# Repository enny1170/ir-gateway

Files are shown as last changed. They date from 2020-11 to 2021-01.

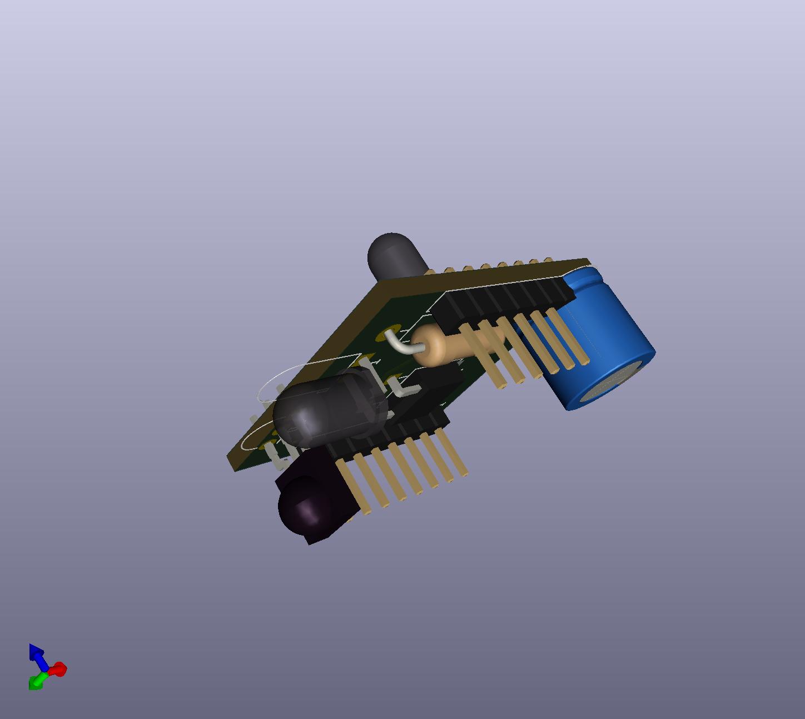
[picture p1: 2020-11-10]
shematics/kicad/RcOid/RcOid/RcOid.jpg

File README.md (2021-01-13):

# Introduction 
This is a fork of the famous [ESP8266-RcOid](https://www.rcoid.de/ESP8266.html) Project

the Hardware is changed to a Wemos D1 mini pro alternativly Wemos D1 32 (pincompatible) and the is software updated to support this.
And a custom Board are developed. To easy hookup this on the Module.
Most parts are rewritten, because I want to use this also as IR-Gateway togeter with my Smart-Home.
So we change to ESP Async-Webser and AsyncMQTT. Adding a better WebUI to support Storage and Management of Codes via Web-Ui.

To have a good Support for multiple Clients at the same Device we have designet to work without any blocking functions.
All API's needed to support the Rcoid-App exist. So the App is fully suported.

This project contains also several shematics.
1. a circurit and a pcb to simply Hookup on the given Module. (shematics/kicad/) [IR-Shield](https://www.pcbway.com/project/shareproject/IR_Shield_for_wemos_D1_pro_or_Wemos_D1_32.html)
2. 3D printable STL-Files as for a Cover (shematic/3dprint)
3. a Freecad Project to build or modify the Case (shematic/freecad)

# Usage (extract from Device Readme)
    This Firmware is a complete new Implementation of the [Rcoid](https://rcoid.de/) Project.
    This implementation supports the same Interface for the RcOid App. Has a extended Web UI and REST-Api. Devices can be used as IR-Gateway trought MQTT. 

    Sending and reciving IR-Codes new implemented for blocking free work. Also the storage of IR-Codes (Commands) added. This Commands can be used for MQTT and REST. 
    Upload and Downlowad of stored commands are possible. 

    A new unconfigured Device will start in Accesspoint-Mode and provide a 'ESP8266 for RCoid Access Point' with Password passpass on IP 192.168.0.1. 
    You are able to setup SSID and Password for your local WiFi-Connection.
    From the Root-Page you have also the possibility tor reboot, remove Web Config, and reset to Factory.
    Only from this page you can enable IR-reciving to capture IR-Codes.
    From the MQTT Page you can ste the Connection to your MQTT-Server and a Prefix used for the topic on MQTT. If the MQTT-Server adress empty or a '.' the MQTT communication will be disabled.
    In MQTT-Broker the device will be provide its local IP-Adress and available commands. The device subscribes /[Prefix]/Cmd. If the device receive a String in this topic, this will be interpreted as a Command. 
    The device try to find this Command and will send the Code immedaly.
    The same Functionality can be reached by sending a GET-Request to /cmd?button=xxxx. Where xxxx the name of the command. It can be taken from the Command-Page.

    The Command page are selfexplanating. But two points you have to know. Editing a Command you have to set a Code and a Name. The Name will be used as Filename to store the command on device Flash.
    And also as Command to raise from MQTT. The Clock Icon on the Command-Page will give you the possibilty to setup one Timer to send this command later.

    Some devices needs to receive a Code multiple times. So we add a Option Repeat for stored Commands. This will repeat the IR-Output according to this setting. Minimum is 1 maximum 5.

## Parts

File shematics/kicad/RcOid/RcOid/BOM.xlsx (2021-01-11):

Reference | Description | Count
U1 | IR Receiver VS1838B | 1
R1 | Resistor 2.4 Ohm | 1
D1 / D2 | IR Sender TSAL6400 (normaly 1 will be used) | 1
Q1 | MOSFET IRLU024N | 1
C1 | ELCO 2000µF radial | 1

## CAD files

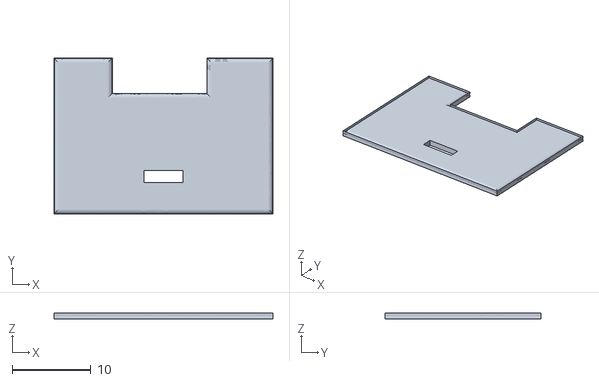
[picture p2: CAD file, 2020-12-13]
shematics/3dprint/RcDroidTop_V2.stl
27.8 x 19.8 x 0.8

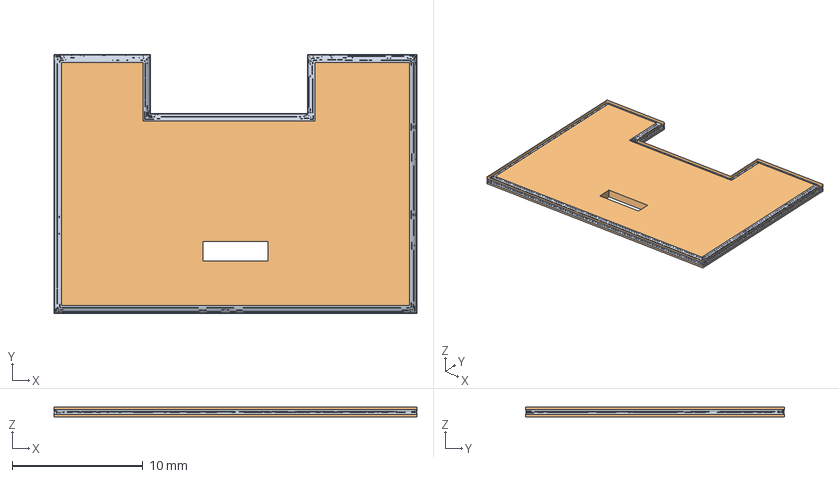
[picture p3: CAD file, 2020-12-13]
shematics/freecad/IrDroid_Case_V2.FCStd
27.8 x 19.8 x 0.8 mm
Top
Top001

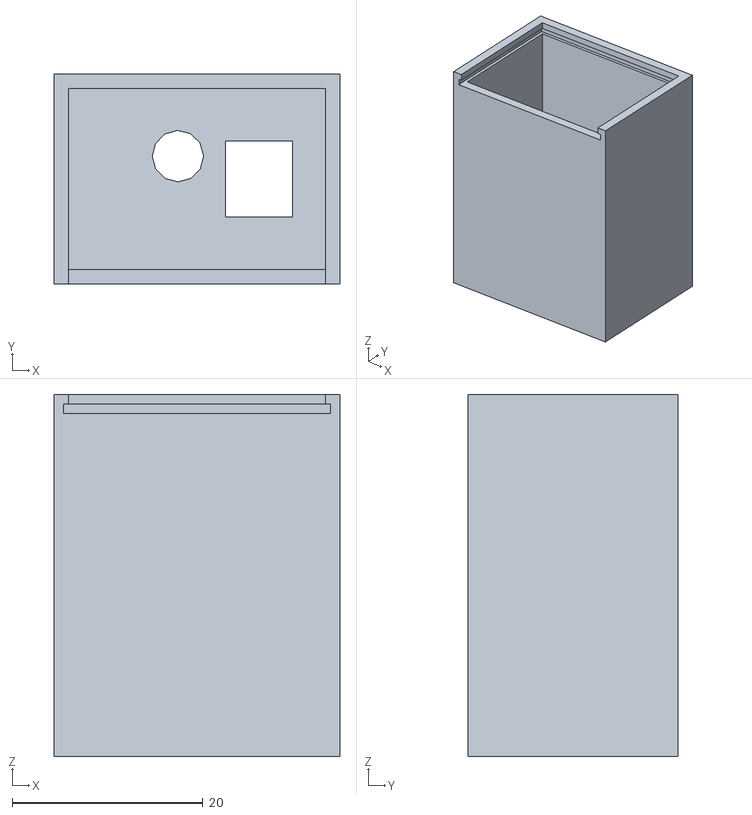
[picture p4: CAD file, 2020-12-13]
shematics/3dprint/RcDroidCase_V2.stl
30.0 x 22.0 x 38.0

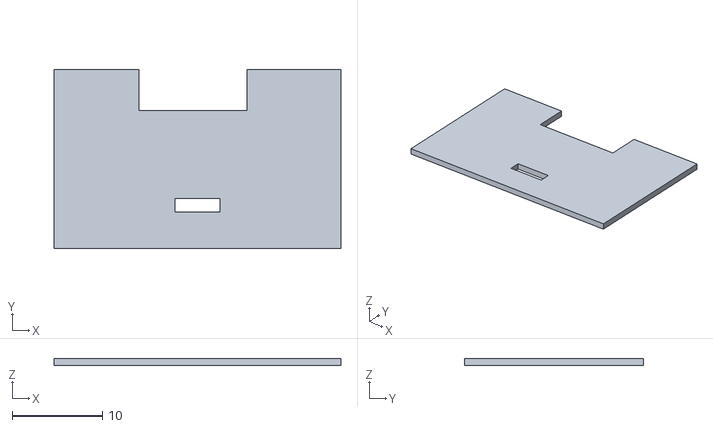
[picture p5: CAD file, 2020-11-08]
shematics/3dprint/IrDroidTop.stl
31.8 x 19.8 x 0.8

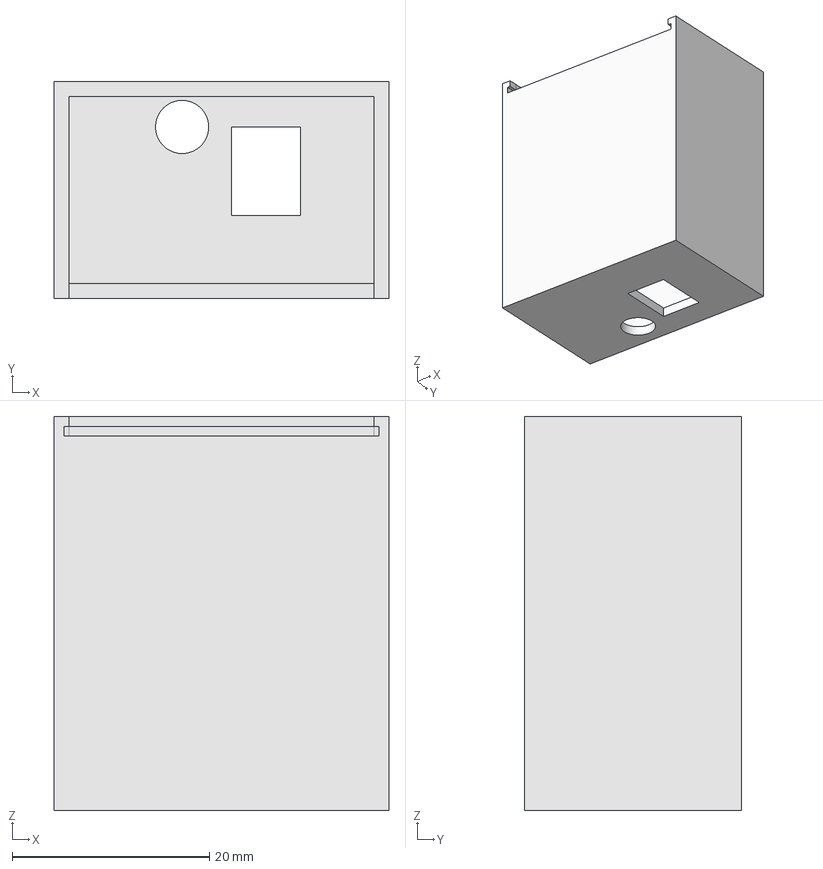
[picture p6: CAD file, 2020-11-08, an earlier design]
shematics/freecad/IrDroid_Case_V1.FCStd
34.0 x 22.0 x 40.0 mm

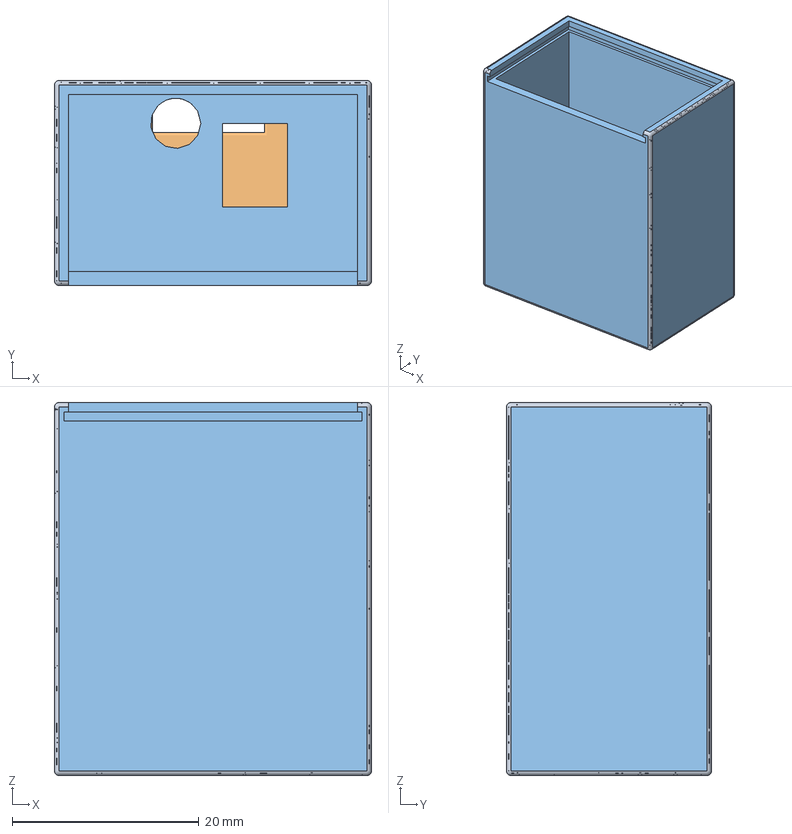
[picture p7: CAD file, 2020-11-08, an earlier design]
shematics/freecad/IrDroid_Case.FCStd
34.0 x 22.0 x 40.0 mm
Case
RcDroidTop_V1
RcDroidCase_V1

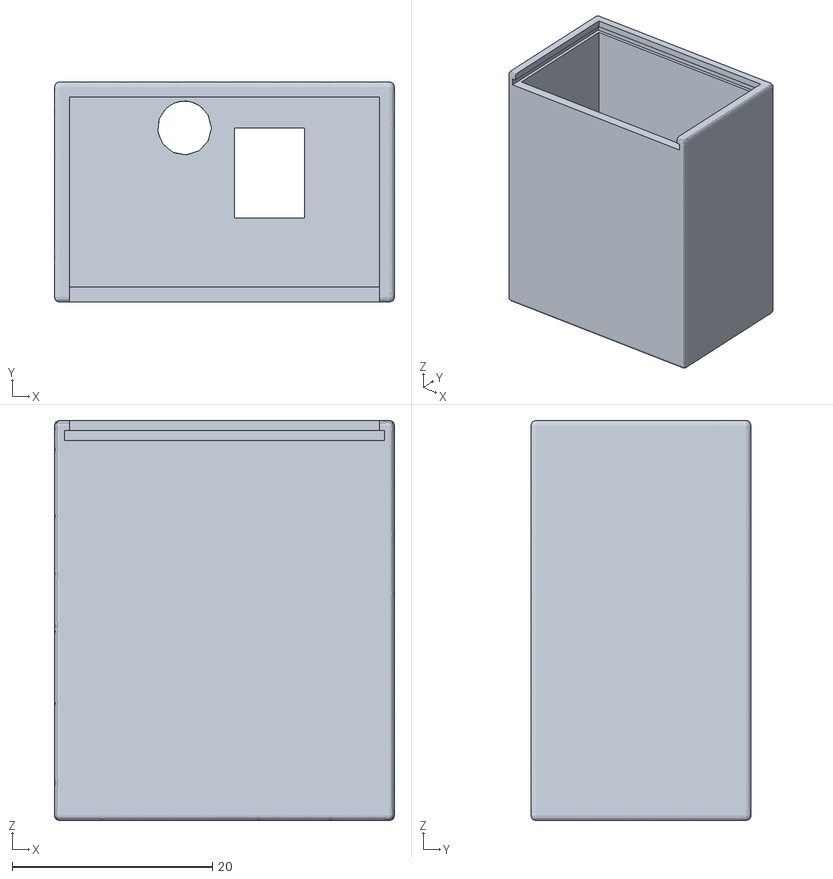
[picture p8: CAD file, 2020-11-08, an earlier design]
shematics/3dprint/RcDroidCase_V1.stl
34.0 x 22.0 x 40.0

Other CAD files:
shematics/3dprint/RcDroidTop_V1.stl
shematics/3dprint/IrDroidCase.stl

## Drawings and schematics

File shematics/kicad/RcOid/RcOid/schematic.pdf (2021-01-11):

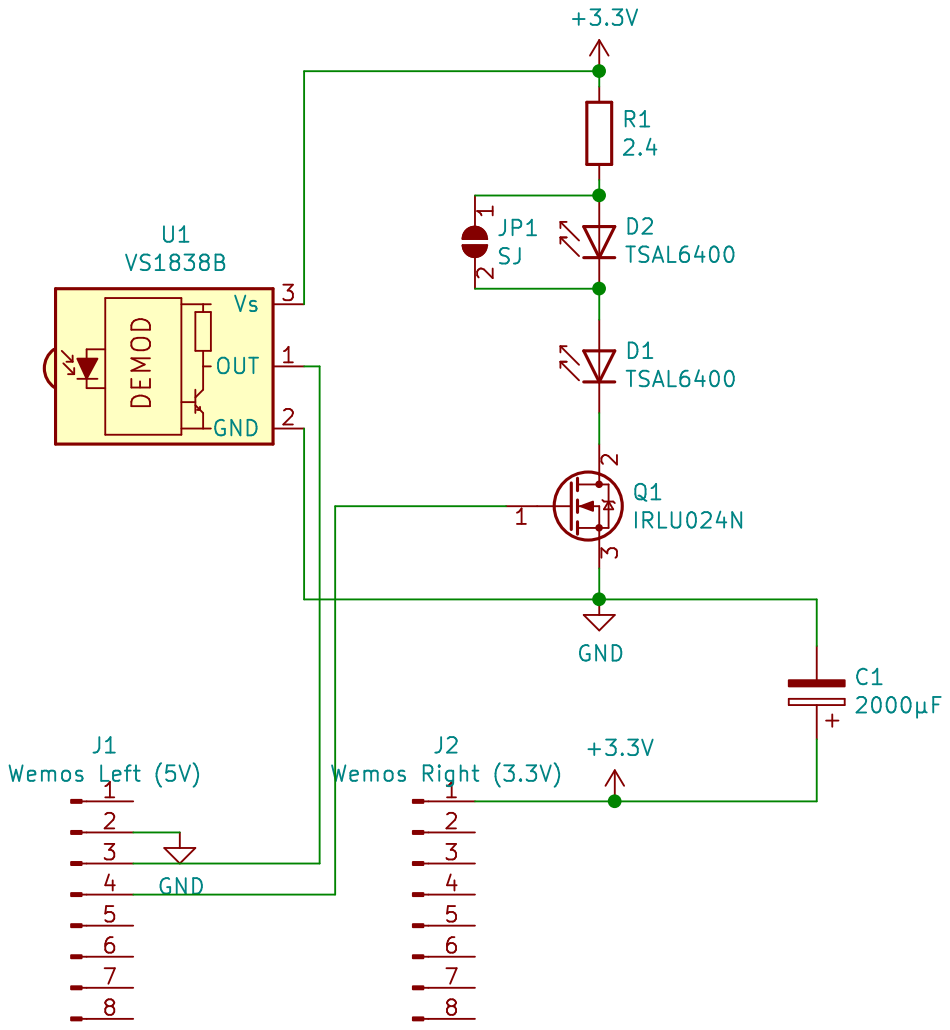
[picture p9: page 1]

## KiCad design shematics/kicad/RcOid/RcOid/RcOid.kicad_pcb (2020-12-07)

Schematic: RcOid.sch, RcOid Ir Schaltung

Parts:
C1: 2000µF; CP_Radial_D10.0mm_P2.50mm
D1: TRU 1577326; LED_D5.0mm_Horizontal_O1.27mm_Z3.0mm_IRGrey
D2: TRU 1577326; LED_D5.0mm_IRGrey
J1: Wemos Left (5V); PinHeader_1x08_P2.54mm_Vertical
J2: Wemos Right (3.3V); PinHeader_1x08_P2.54mm_Vertical
JP1: SJ; SolderJumper-2_P1.3mm_Open_Pad1.0x1.5mm
Q1: IRLU024N; TO-251-2-1EP_Horizontal_TabDown
R1: 47; R_Axial_DIN0411_L9.9mm_D3.6mm_P15.24mm_Horizontal
U1: TSOP531xx; Vishay_MINIMOLD-3Pin

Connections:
+3V3: C1.1, J2.1, R1.1, U1.3 (Vs)
GND: C1.2, J1.2, Q1.3 (S), U1.2 (GND)
unnamed: D1.1 (K), Q1.2 (D)
unnamed: D1.2 (A), D2.1 (K), JP1.2
unnamed: D2.2 (A), JP1.1, R1.2
unnamed: J1.3, U1.1 (OUT)
unnamed: J1.4, Q1.1 (G)

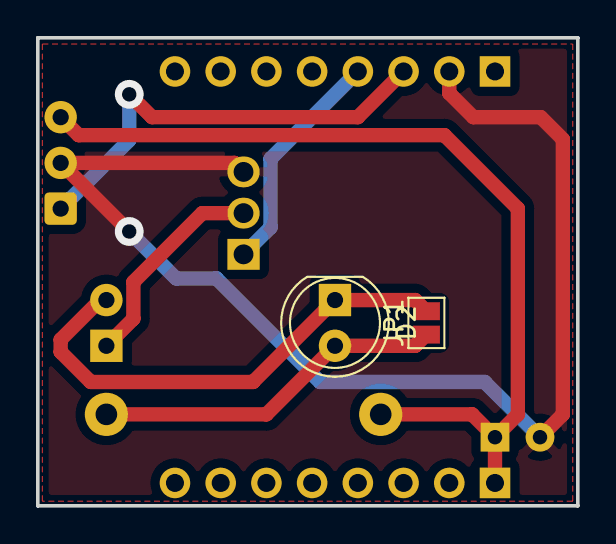
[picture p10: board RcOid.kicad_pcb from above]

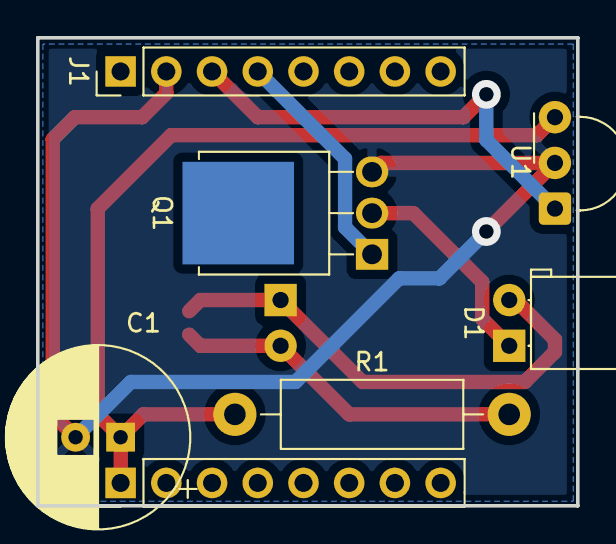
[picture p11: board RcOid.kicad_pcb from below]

Board: 2 copper layers, 30.0 x 26.0 mm, 9 parts (7 on the bottom side), 7 nets.

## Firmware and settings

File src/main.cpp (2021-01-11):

#include <WiFiClient.h>
#include <Arduino.h>
#ifdef ESP32
#include <WiFi.h>
#include <AsyncTCP.h>
#elif defined(ESP8266)
#include <ESP8266WiFi.h>
#include <ESPAsyncTCP.h>
#endif
#include <ESPAsyncWebServer.h>
#include <IRremoteESP8266.h>
#include <IRrecv.h>
#include <IRutils.h>
#include <ArduinoJson.h>
#include <Config.h>
#include <mqttconf.h>
#include <WebServerImpl.h>
#include <ircode.h>
#include <ircodes.h>
#include <mqttimpl.h>
#include <ArduinoOTA.h>

// The IR Hardware are defined in ircodes.h

// Netzwerkinformationen für Accesspoint
// Im AP-Modus ist der ESP8266 unter der IP 192.168.0.1 erreichbar
const char *ssidAP = "ESP8266 for RCoid Access Point";
const char *passwordAP = "passpass"; //Muss mindestens 8 Zeichen haben
//bool startMqtt=false;



/***********************************************************************************************************
    ////////////////////////////////////   SETUP Access Point  ///////////////////////////////////////////

    Create Soft AP.
    Settings:
        SSID = "ESP8266 for RCoid Access Point"
        Pass = "passpass"
        IP   = "192.168.0.1"

    Will be done if no Wifi configured.
************************************************************************************************************/
void setupAP(void)
{
  WiFi.mode(WIFI_AP_STA);

  serial_print_Networks();

  Serial.println("Setup Soft AP...");
  IPAddress apIP(192, 168, 0, 1);
  WiFi.softAPConfig(apIP, apIP, IPAddress(255, 255, 255, 0));

  WiFi.softAP(ssidAP, passwordAP, 3, false);
  delay(100);
  configureWebServer();
#ifdef LED_BUILTIN
  digitalWrite(LED_BUILTIN, LOW);
#endif
  Serial.println("Soft AP 'ESP8266 for RCoid Access Point' online");
}


/********************************************************************************************
 * ////////////////////////////////////   SETUP   ///////////////////////////////////////////
*********************************************************************************************/
void setup(void)
{

  pinMode(IR_PORT, OUTPUT);
  digitalWrite(IR_PORT, IR_PORT_INVERT ? HIGH : LOW);
#ifdef LED_BUILTIN
  pinMode(LED_BUILTIN, OUTPUT);
  digitalWrite(LED_BUILTIN, HIGH);
#else
  //ESP32 devKit V2 has no onboard LED only Power
#endif
  Serial.begin(115200);
  delay(50);
  //assert(irutils::lowLevelSanityCheck() == 0);
  initFileSystem();
  delay(5);
  setupWiFiEvents();
  setupMqttEvents();
  checkConfig();
  checkMqttConfig();
  // try to load Config
  readConfig();
#ifdef ESP8266
    //configure Webserver on esp8266 here because ESP32 implementation is different
    configureWebServer();
#endif
  setupMqtt();

  Serial.println("-- WiFi - Config --");
  Serial.println(getESPDevName());
  Serial.print("SSID: ");
  Serial.println(ssid);
  Serial.print("PASS: ");
  Serial.println(passwd);
  Serial.print("DeviceName: ");
  Serial.println(deviceName);
  Serial.print("MAC: ");
  Serial.println(WiFi.macAddress());
  if(ssid.length()>1)
  {
    WiFi.mode(WIFI_STA);
    Serial.println("Start Wifi");
    connectToWiFi();
    ArduinoOTA.begin();
  }
  else
  {
    Serial.print("Setup Accespoint");
    setupAP();
  }
  #ifdef ESP32
    configureWebServer();
  #endif
  Serial.println("Setup finished");
}

/***********************************************************************************
 * Main Loop
************************************************************************************/
void loop()
{
  //Call the IR Receiver Handler
  receive_ir_nonblock(true);
  sendIrCodeFromQueue();
  cmdTimer.update();
  ArduinoOTA.handle();
}

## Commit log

2020-11-08 first checkin
    [IrDroidCase.stl, IrDroidTop.stl, IrDroid_Case.FCStd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]
2020-11-08 Schematc Update
    [RcOid.sch]
2020-11-08 change R
    [RcOid.sch]
2020-11-08 Case V1
    [IrDroid_Case.FCStd, IrDroid_Case_V1.FCStd, RcDroidCase_V1.stl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]
2020-11-10 TH PCB
    [RcOid.kicad_pcb, RcOid.sch]
2020-11-30 reset casue 4 ka warum
    [main.cpp]
2020-12-01 change pcb layout
    [RcOid-B_Cu.gbr, RcOid-B_SilkS.gbr, RcOid-Edge_Cuts.gbr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]
2020-12-03 fix solder Mask
    [RcOid-B_Cu.gbr, RcOid-B_Mask.gbr, RcOid-B_SilkS.gbr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]
2020-12-03 add esp32 Build
2020-12-04 ESP32 läuft 8266 reboot 4
    [main.cpp]
2020-12-07 fix PCB wrong Footprint
    [RcOid-B_Cu.gbr, RcOid-B_Mask.gbr, RcOid-B_SilkS.gbr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]
2020-12-13 V2 Mechanics
    [IrDroid_Case_V2.FCStd, RcDroidCase_V2.stl, RcDroidTop_V2.stl]
2020-12-22 ESP32 is running on this code
2020-12-29 Werte aktualisiert
    [RcOid.sch]
2021-01-09 finish Timer and Readme
2021-01-11 ready for publish
    [BOM.xlsx, RcOid.sch]
